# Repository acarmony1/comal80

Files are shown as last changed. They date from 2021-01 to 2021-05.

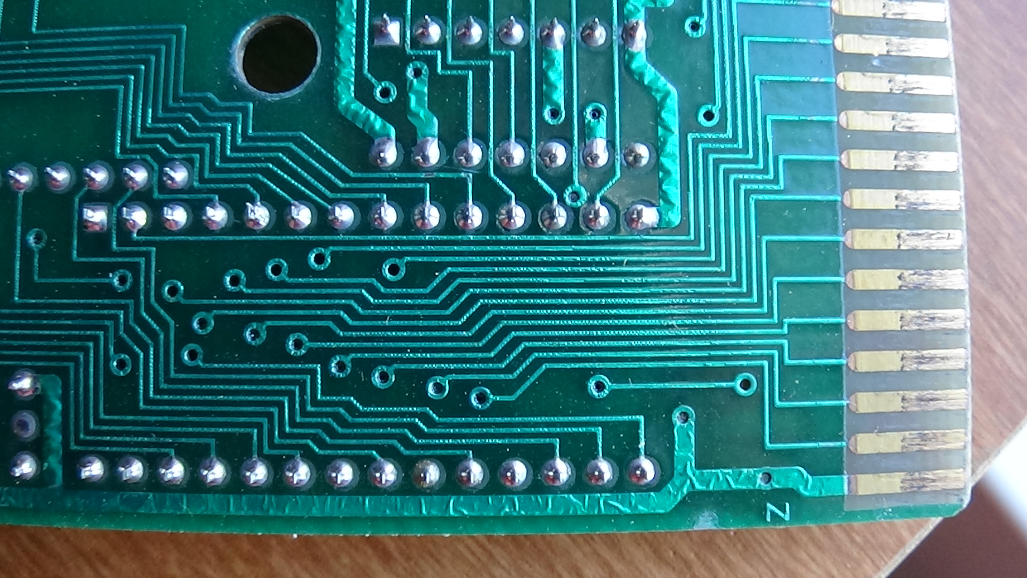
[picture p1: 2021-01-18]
C64/reference/comal80cartridgepictures/DSC02221.JPG

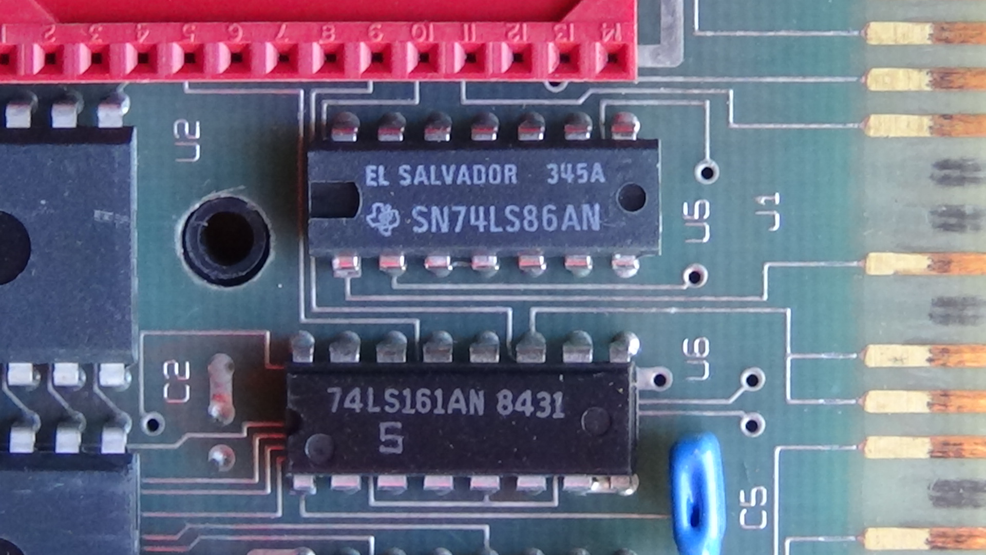
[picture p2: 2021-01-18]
C64/reference/comal80cartridgepictures/DSC02206.JPG

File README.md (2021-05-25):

# comal80
COMAL 80 for C64
https://carmony.xyz/10-commodore/commodore-64-projects/2-comal-80-for-the-c64.html

or visit https://carmony.xyz for other infomation.

In December of 2020 I was asked by KEN SIMMONS to create a comal-80 cartridge, for the Commodore 64, from an old COMAL TODAY magazine schematic. The COMAL80 cartridge uses unique 'bankswithcing' to switch up to 96KB of ROM.

This project is a result of that task. 

The board is a simple 2 layer design, with (3) 27C256 EPROMS, and (3) logic devices (74LS86, 74LS161, 74LS139), others may be substitued but are not known at this time.

The gerber files for creating a PCB are located in the gerbers directory. The bin files for U1 and U2 are located in the bin folder. U3 is left empty, and is used for personal space (if needed) for user applications, called packages. There is a 'superchip' that existed to allow for expansion of the COMAL 80 system, however I cannot locate this bin currently.

1-18-2021	GutHub creation and release of V1. Design is known working and completed. No known issues or releases planned. 

1-19-2021 C64/C128 folders added. C128 Comal Cartridge schematic added.

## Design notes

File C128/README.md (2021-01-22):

# comal80
COMAL 80 for C128

In December of 2020 I was asked by KEN SIMMONS to create a comal-80 cartridge, for the Commodore 64, from an old COMAL TODAY magazine schematic. The COMAL80 cartridge uses unique 'bankswithcing' to switch up to 96KB of ROM.

This project is a result of that task. 

The board is a simple 2 layer design, with (3) 27C256 EPROMS, and (4) logic devices (74LS00, 74LS125N, 74LS161, 74LS139), others may be substitued but are not known at this time.

1-21-2021 Deemed C128 schematic un-useable, it is not correct. Various errors. Do not use!

1-19-2021 C64/C128 folders added. C128 Comal Cartridge schematic added. Updated readme.md for each. Added C128 ROM files (U1, U2, U3)

1-18-2021	GutHub creation and release of V1. Design is known working and completed. No known issues or releases planned.

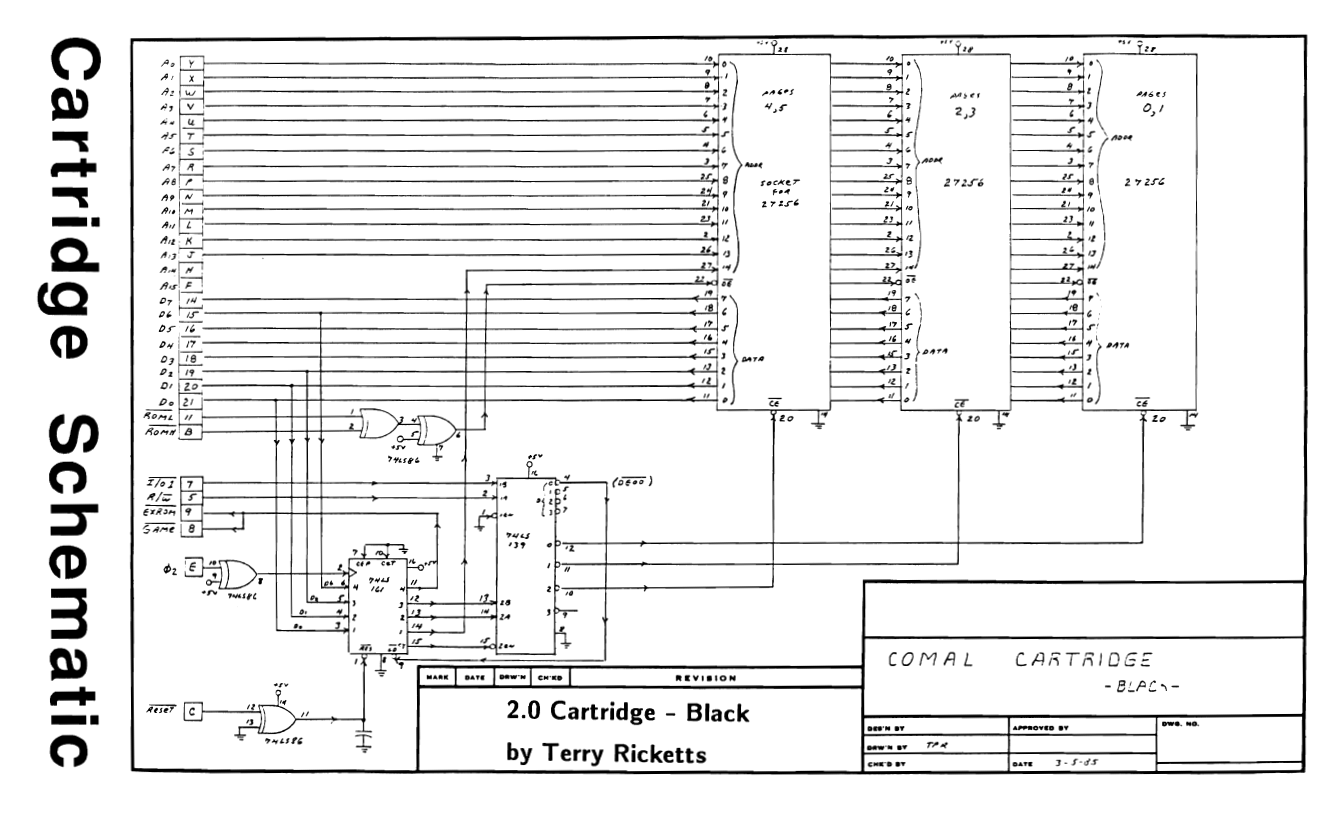
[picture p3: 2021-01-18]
C64/Comal Black Cartridge schematic(orig).png

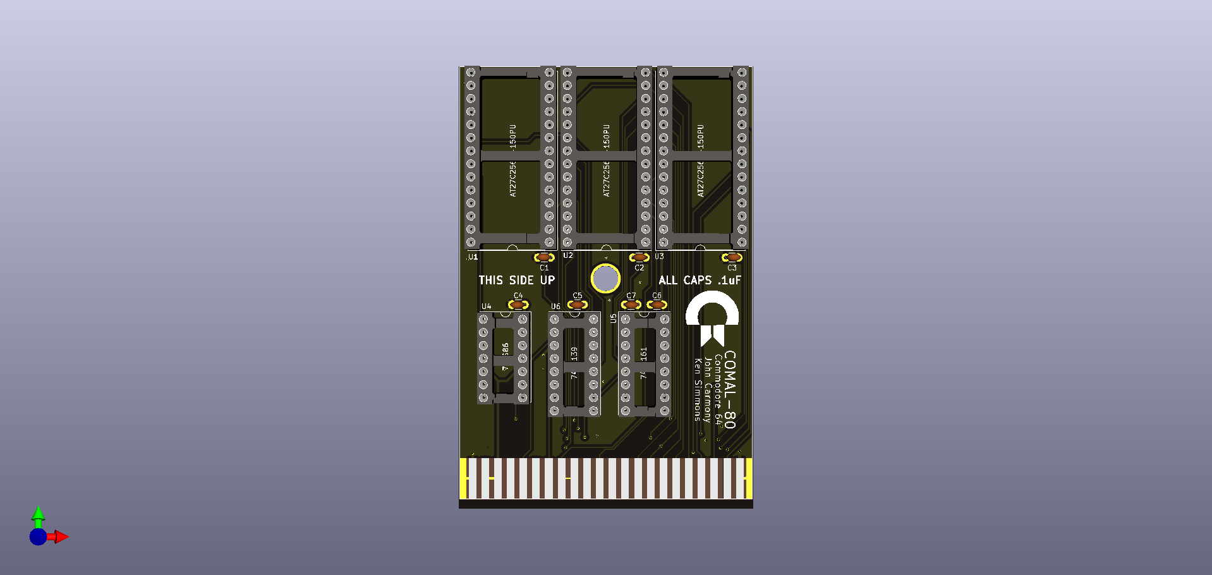
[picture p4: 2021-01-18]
C64/comal-80-3d.png

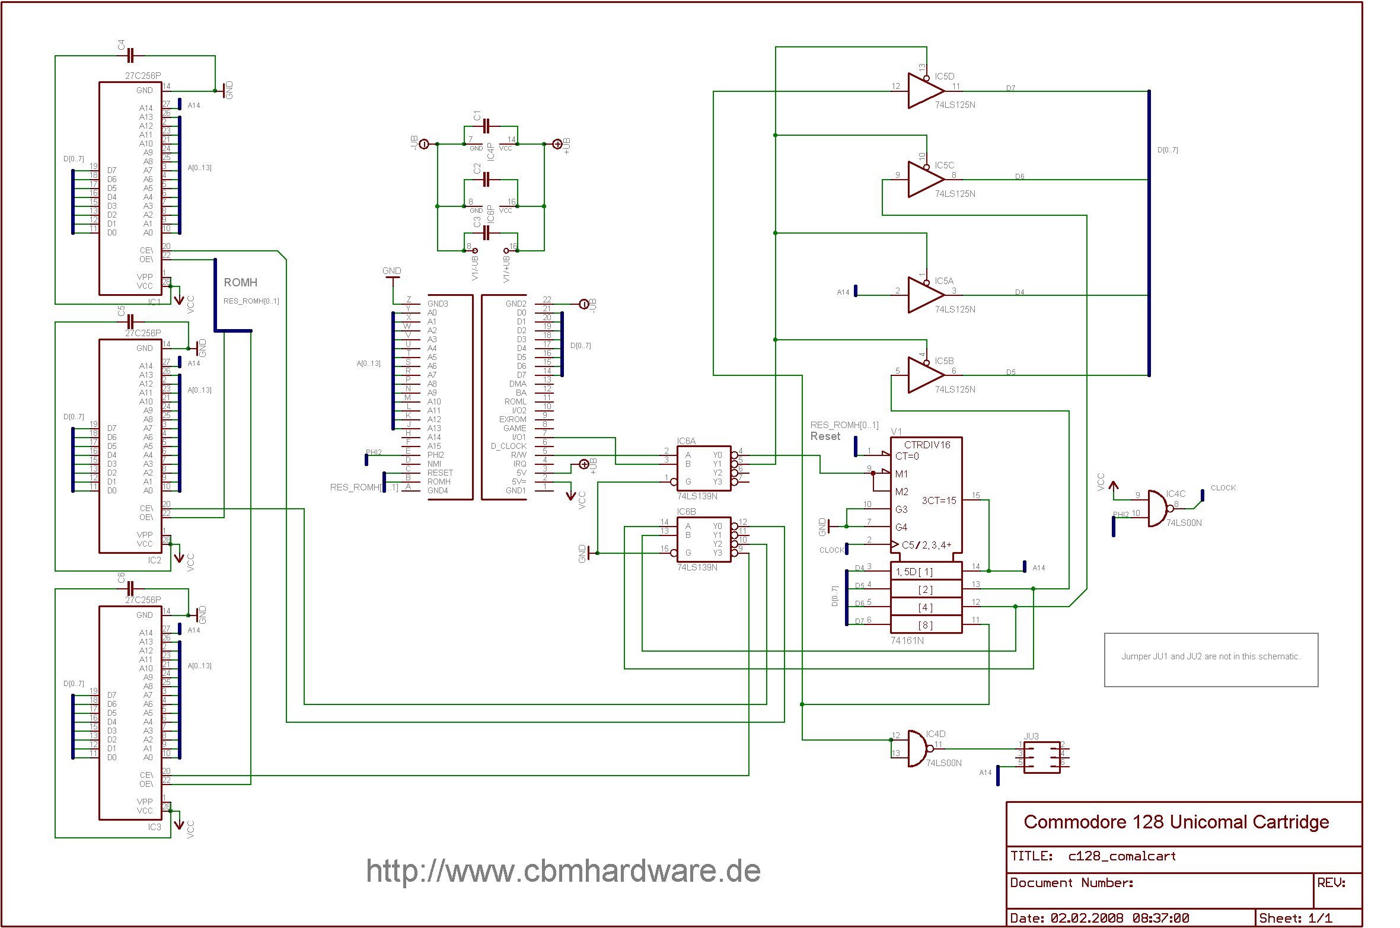
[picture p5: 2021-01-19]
C128/c128_comal80_logic.jpg

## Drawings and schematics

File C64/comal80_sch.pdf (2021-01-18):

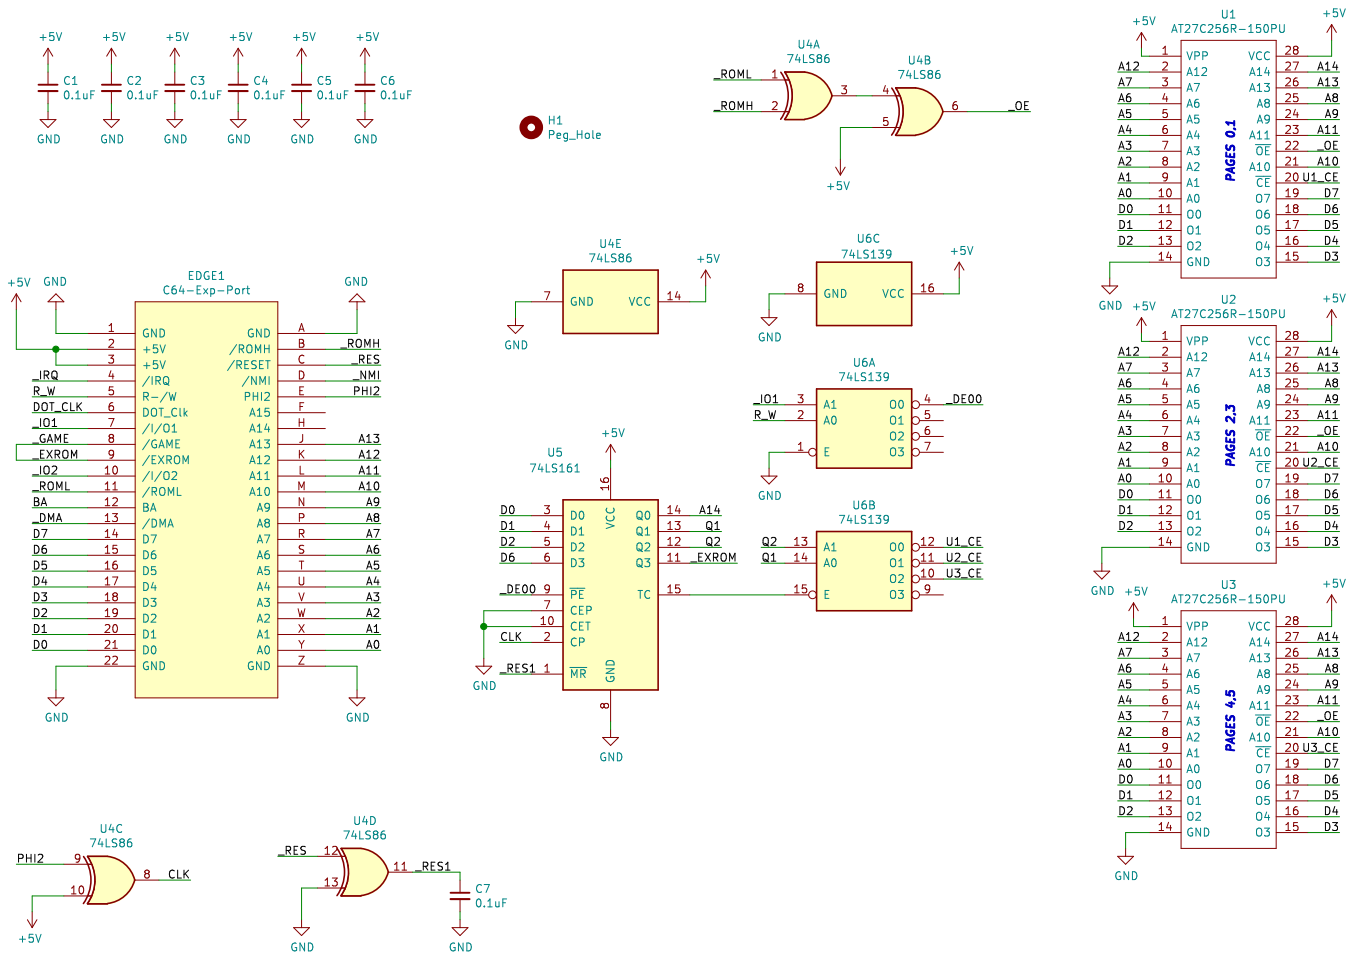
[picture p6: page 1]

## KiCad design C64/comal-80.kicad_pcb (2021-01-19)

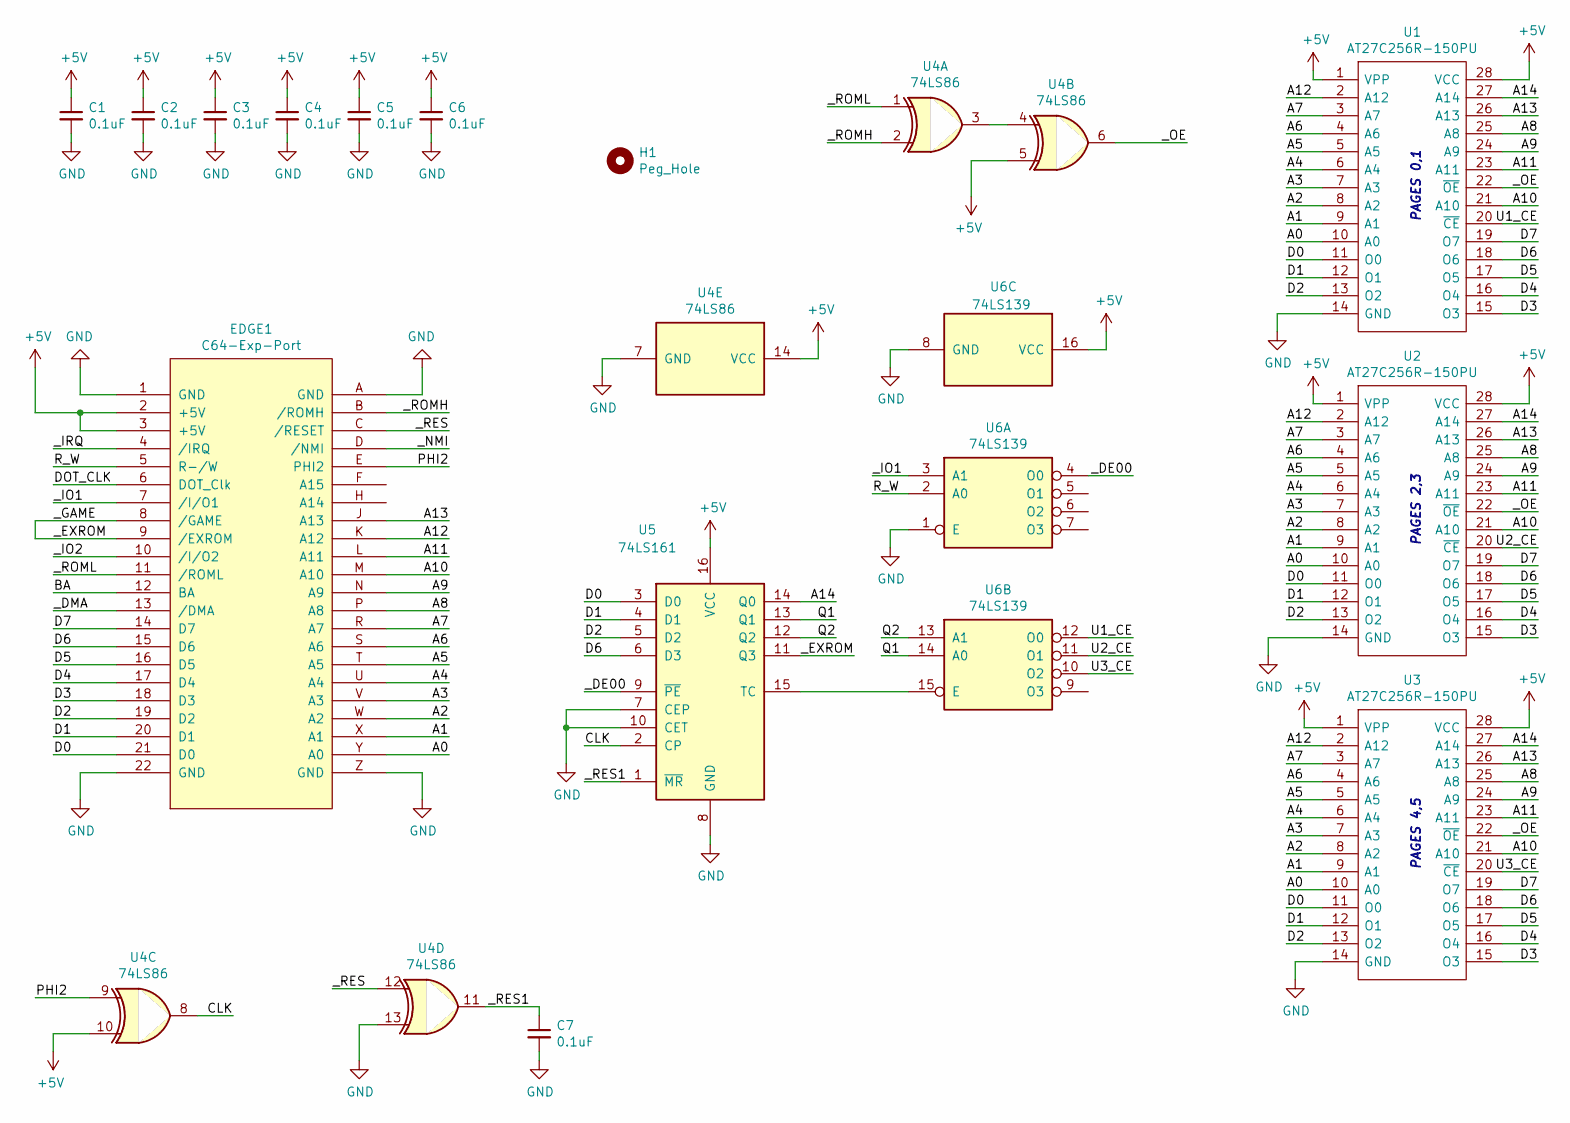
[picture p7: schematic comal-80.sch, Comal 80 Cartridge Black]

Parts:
C1, C2, C3, C4, C5, C6, C7: 0.1uF; C_Disc_D3.0mm_W1.6mm_P2.50mm
EDGE1: C64-Exp-Port; C64-Cart
H1: Peg_Hole; MountingHole_5mm_Pad
U1, U2, U3: AT27C256R-150PU; DIP-28_W15.24mm_Socket; Manufacturer_Part_Number AT27C256R-70PU; Mouser Part Number 556-AT27C256R70PU
U4: 74LS86; DIP-14_W7.62mm_Socket
U5: 74LS161; DIP-16_W7.62mm_Socket
U6: 74LS139; DIP-16_W7.62mm_Socket

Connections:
+5V: C1.1, C2.1, C3.1, C4.1, C5.1, C6.1, EDGE1.2 (+5V), EDGE1.3 (+5V), U1.1 (VPP), U1.28 (VCC), U2.1 (VPP), U2.28 (VCC), U3.1 (VPP), U3.28 (VCC), U4.5, U4.10, U4.14 (VCC), U5.16 (VCC), U6.16 (VCC)
/A0: EDGE1.Y (A0), U1.10 (A0), U2.10 (A0), U3.10 (A0)
/A1: EDGE1.X (A1), U1.9 (A1), U2.9 (A1), U3.9 (A1)
/A2: EDGE1.W (A2), U1.8 (A2), U2.8 (A2), U3.8 (A2)
/A3: EDGE1.V (A3), U1.7 (A3), U2.7 (A3), U3.7 (A3)
/A4: EDGE1.U (A4), U1.6 (A4), U2.6 (A4), U3.6 (A4)
/A5: EDGE1.T (A5), U1.5 (A5), U2.5 (A5), U3.5 (A5)
/A6: EDGE1.S (A6), U1.4 (A6), U2.4 (A6), U3.4 (A6)
/A7: EDGE1.R (A7), U1.3 (A7), U2.3 (A7), U3.3 (A7)
/A8: EDGE1.P (A8), U1.25 (A8), U2.25 (A8), U3.25 (A8)
/A9: EDGE1.N (A9), U1.24 (A9), U2.24 (A9), U3.24 (A9)
/A10: EDGE1.M (A10), U1.21 (A10), U2.21 (A10), U3.21 (A10)
/A11: EDGE1.L (A11), U1.23 (A11), U2.23 (A11), U3.23 (A11)
/A12: EDGE1.K (A12), U1.2 (A12), U2.2 (A12), U3.2 (A12)
/A13: EDGE1.J (A13), U1.26 (A13), U2.26 (A13), U3.26 (A13)
/A14: U1.27 (A14), U2.27 (A14), U3.27 (A14), U5.14 (Q0)
/BA: EDGE1.12 (BA)
/CLK: U4.8, U5.2 (CP)
/D0: EDGE1.21 (D0), U1.11 (O0), U2.11 (O0), U3.11 (O0), U5.3 (D0)
/D1: EDGE1.20 (D1), U1.12 (O1), U2.12 (O1), U3.12 (O1), U5.4 (D1)
/D2: EDGE1.19 (D2), U1.13 (O2), U2.13 (O2), U3.13 (O2), U5.5 (D2)
/D3: EDGE1.18 (D3), U1.15 (O3), U2.15 (O3), U3.15 (O3)
/D4: EDGE1.17 (D4), U1.16 (O4), U2.16 (O4), U3.16 (O4)
/D5: EDGE1.16 (D5), U1.17 (O5), U2.17 (O5), U3.17 (O5)
/D6: EDGE1.15 (D6), U1.18 (O6), U2.18 (O6), U3.18 (O6), U5.6 (D3)
/D7: EDGE1.14 (D7), U1.19 (O7), U2.19 (O7), U3.19 (O7)
/DOT_CLK: EDGE1.6 (DOT_Clk)
/PHI2: EDGE1.E (PHI2), U4.9
/Q1: U5.13 (Q1), U6.14 (A0)
/Q2: U5.12 (Q2), U6.13 (A1)
/R_W: EDGE1.5 (R-/W), U6.2 (A0)
/U1_CE: U1.20 (~CE), U6.12 (O0)
/U2_CE: U2.20 (~CE), U6.11 (O1)
/U3_CE: U3.20 (~CE), U6.10 (O2)
/_DE00: U5.9 (~PE), U6.4 (O0)
/_DMA: EDGE1.13 (/DMA)
/_EXROM: EDGE1.8 (/GAME), EDGE1.9 (/EXROM), U5.11 (Q3)
/_IO1: EDGE1.7 (/I/O1), U6.3 (A1)
/_IO2: EDGE1.10 (/I/O2)
/_IRQ: EDGE1.4 (/IRQ)
/_NMI: EDGE1.D (/NMI)
/_OE: U1.22 (~OE), U2.22 (~OE), U3.22 (~OE), U4.6
/_RES: EDGE1.C (/RESET), U4.12
/_RES1: C7.1, U4.11, U5.1 (~MR)
/_ROMH: EDGE1.B (/ROMH), U4.2
/_ROML: EDGE1.11 (/ROML), U4.1
GND: C1.2, C2.2, C3.2, C4.2, C5.2, C6.2, C7.2, EDGE1.1 (GND), EDGE1.22 (GND), EDGE1.A (GND), EDGE1.Z (GND), U1.14 (GND), U2.14 (GND), U3.14 (GND), U4.7 (GND), U4.13, U5.7 (CEP), U5.8 (GND), U5.10 (CET), U6.1 (E), U6.8 (GND)
unnamed: U4.3, U4.4
unnamed: U5.15 (TC), U6.15 (E)

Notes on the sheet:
PAGES 4,5
PAGES 2,3
PAGES 0,1

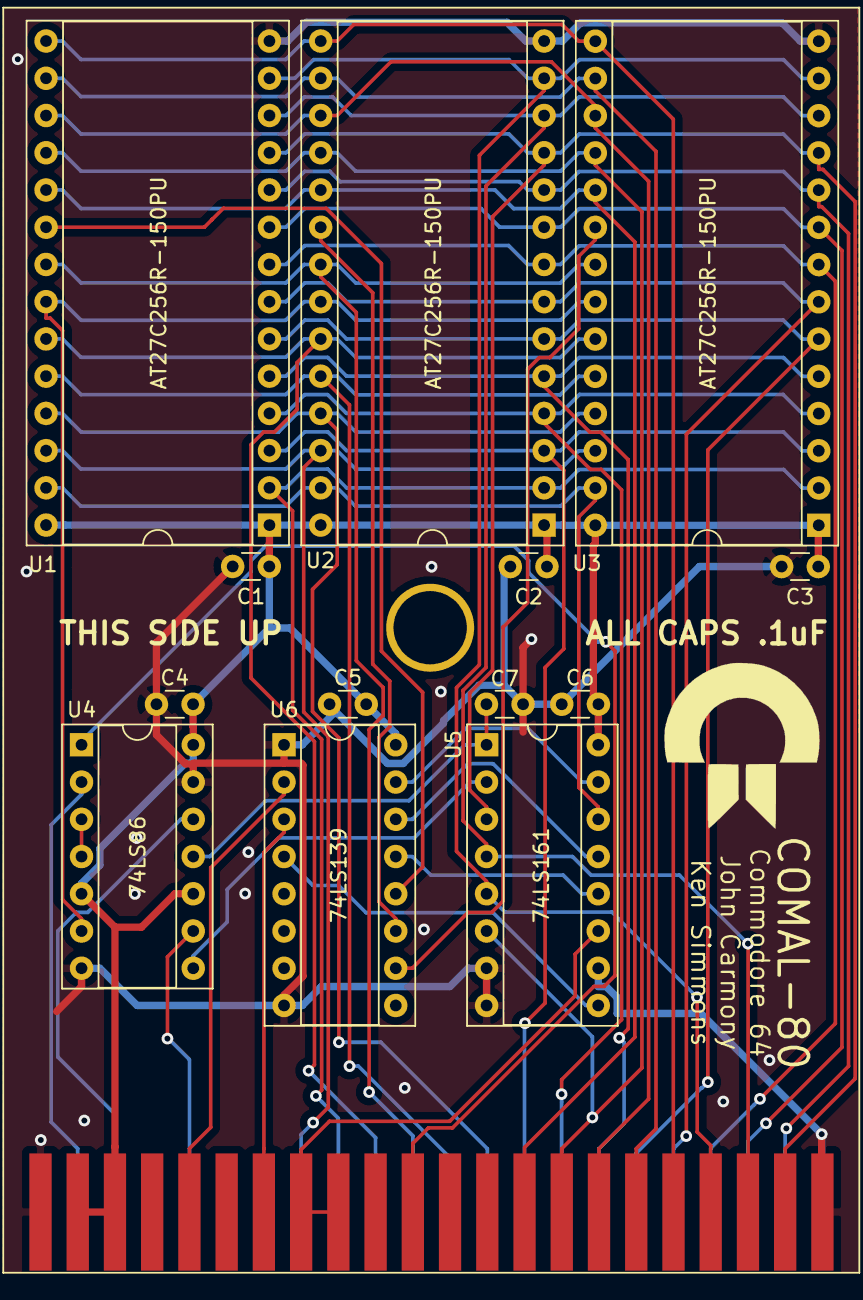
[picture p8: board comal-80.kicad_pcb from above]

Board: 2 copper layers, 15 parts (0 on the bottom side), 43 nets.

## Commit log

2021-01-18 First update
    [comal-80 - Copy.kicad_pcb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]
2021-01-18 Schematic Housekeeping
    Adjustments made to schematic, updated PDF
    [comal-80.sch]
2021-01-18 Added 3D pic
    [comal-80.kicad_pcb]
2021-01-18 Delete comal-80 - Copy.kicad_pcb
    removed some files.
    [comal-80 - Copy.kicad_pcb]
2021-01-18 Create Comal Black Cartridge schematic(orig).png
2021-01-19 Added C128 schematic
    Created C64 and C128 folders and added C128 comal cart schematic
    [comal-80-B_Cu.gbr, comal-80-B_Mask.gbr, comal-80-B_Paste.gbr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]
2021-01-22 Updated C128 README.md
    C128 schematic is un-useable

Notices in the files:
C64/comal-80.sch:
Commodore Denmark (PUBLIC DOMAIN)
